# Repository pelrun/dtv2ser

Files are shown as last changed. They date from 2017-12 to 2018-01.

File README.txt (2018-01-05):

README.txt

        dtv2ser - a serial bridge device for the dtvtrans protocol

            written by Christian Vogelgsang <chris@vogelgsang.org>
            under the GNU Public License V2
            
            Homepage: http://www.lallafa.de/blog

Abstract
--------

dtvtrans is a data transfer tool and a PC parallel port cable that allows to
directly read or write memory from a DTV (a.k.a. C64 in a Joystick) via its
joystick or userport. dtvtrans is developed by Daniel Kahlin/TLR and
available here:

  http://www.kahlin.net/daniel/dtv/cable.php

dtv2ser is a small hardware device that implements the dtvtrans protocol on an
Atmel ATmega8 microcontroller. The transferred data is then passed through a
RS232 high speed serial link to a connected client computer. With this device
all PCs with RS232 can use the dtvtrans protocol. With a serial-to-USB adapter
the dtv2ser device can be connected to almost all modern hardware. The new
dtv2usb device directly combines the serial-to-USB adapter and is realized
on a small USB stick like board.

The data flow is as follows:

 DTV  <--[dtvtrans]-->  dtv2ser  <--[RS232]--> serial-to-usb <--[USB]--> client PC
                        +--------------------v-------------+
                                          dtv2usb

Features
--------
 
The dtv2ser package currently consists of the following parts:

 1.) Hardware
  - 0.2: a new schematic for an ATmega8 based board with included USB serial 
    converter using a FT 232 RL chip: dtv2usb
  - 0.2: ready-made board layout for a dtv2usb "stick-like" SMD board
  - a schematic for a minimal ATmega8 board: dtv2ser with MAX232A based 
    RS232 connection
  - both boards running at 14.54760 MHz
  - 3 LEDs for Status: "Ready" (green), "Transmit" (yellow), "Error" (red)
  - wiring for the dtvtrans DB-9 connector
  - on board 10 pin ISP connector that is also used for the bootloader jumper,
    an optional reset switch and optional external power supply.
  - dtv2usb: on board 3 pin power selector: either from USB or external
  - 0.5: added Arduino 2009 board support.
  - 0.6: added ARM blue pill port (see README.arm.txt)
  --> see hardware/ directory
 
 2.) dtv2ser Server Firmware
  - implements all dtvtrans commands
  - a full featured firmware with rich command set
  - full description of the dtv2ser serial protocol (see doc/dtv2ser-proto.txt)
  - high speed UART serial transfer up to 230.4 kbps
  - hardware RTS/CTS handshaking, 8 bit data, parity none, 1 stop bit
  - config parameters settable during runtime and storable in EEPROM
  - added a bootloader to update the firmware directly via serial without ISP
  --> see server/ directory
 
 3.) dtv2sertrans Client Tool
  - dtv2sertrans command line tool (similar to original dtvtrans tool)
  - python module for dtv2ser communication
  - portable: runs on Mac, Linux and Windows
  - requires PySerial (http://pyserial.sourceforge.net/)
  --> see client/ directory

 NOTE: for Linux Users with dtv2ser+usb Hardware:
  the linux kernel driver for the FT232RL device is broken in some
  kernel releases! with those dtv2sertrans won't work!
  tested ok:    2.6.18
  tested ERROR: 2.6.22
  tested ok:    2.6.24

More Documentation
------------------

In the "docs" directory you will find more documentation on this project.

Here is a summary:

  dtv2ser-setup.txt         Setup your dtv2ser device and the dtv2sertrans
                            client command
                            
  dtv2ser-examples.txt      Usage examples of the dtv2sertrans command tool
  
  dtv2ser-joystick.txt      The new joystick, auto type and bootstrap
                            features added in version 0.3
  
  dtv2ser-proto.txt         A detailed description of the low level dtv2ser
                            protocol used by the host PC to communicate with
                            the dtv2ser device.

  avr-toolchain.txt         The commands I used to build a cross compiler
                            toolchain used to compile the server firmware.

Hardware Documents (located in the "hardware" directory):

  dtv2ser.pdf/.png          Schematics of the dtv2ser board
  dtv2ser.sch               Eagle schematic of dtv2ser board
  
  dtv2usb-sch.pdf/.png      Schematics of the dtv2ser+usb board
  dtv2usb-sch.sch           Eagle schematic of dtv2ser+usb board
 
  dtv2usb-manual.txt        Usage instructions for the dtv2ser+usb device
  dtv2usb-parts.txt         Parts list for the dtv2ser+usb device

  dtv2ser-arduino.txt       Instructions for Arduino 2009 HW setup

Have Fun,
-chris/lallafa
2.3.2008

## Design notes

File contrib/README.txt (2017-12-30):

The files found here are directly taken from the dtvtrans-1.0.zip source
archive and provided here for your convenience.

All credits are due to Daniel Kahlin/TLR, the original author.
The original archive is found here: http://www.kahlin.net/daniel/dtv/cable.php

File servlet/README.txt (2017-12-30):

README.txt
----------

This directory contains the assembler source code for 'servlets' that run on
the DTV. A servlet is first downloaded to the DTV memory and then a sys call
is launched.

You need the DASM assembler to build the source:
http://dasm-dillon.sourceforge.net/

The following servlets are available:

 * diag_srv.asm
   
   a small test program used for the diag sys command.
   
   org: 0x1000
   in:  ACC=<number of frames to execute>
   out: ACC=42
        XR=<number of frames to execute>
        YR=0

 * flash_srv.asm
 
   a helper for the flash operations.
   
   the source includes flash_io.asm written by Daniel Kahlin/TLR
   and was taken from his flash-1.0.zip source distribution.
   see: http://www.kahlin.net/daniel/dtv/flash.php
   
   commands in servlet:

   id:  identify flash
   org: 0x1000
   in:  -
   out: ACC = flash type

   id:  generate flash map
	 org: 0x1003
	 in:  -
	 out: 0x2000-0x2800  flash map in ASCII
   
   id:  flash operation
   org: 0x1006
   in:  ACC = mode (0=erase 1=program 2=verify 3=check_empty)
        0x2000-0x2002: <start lsb>,<start csb>,<start msb>
        0x2003-0x2005: <end lsb>,<end csb>,<end lsb>
   out: ACC = error (0=ok)
        XR  = check_empty_result ($ff=empty)

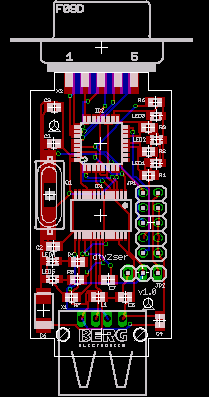
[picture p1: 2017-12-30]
hardware/dtv2usb-brd.png

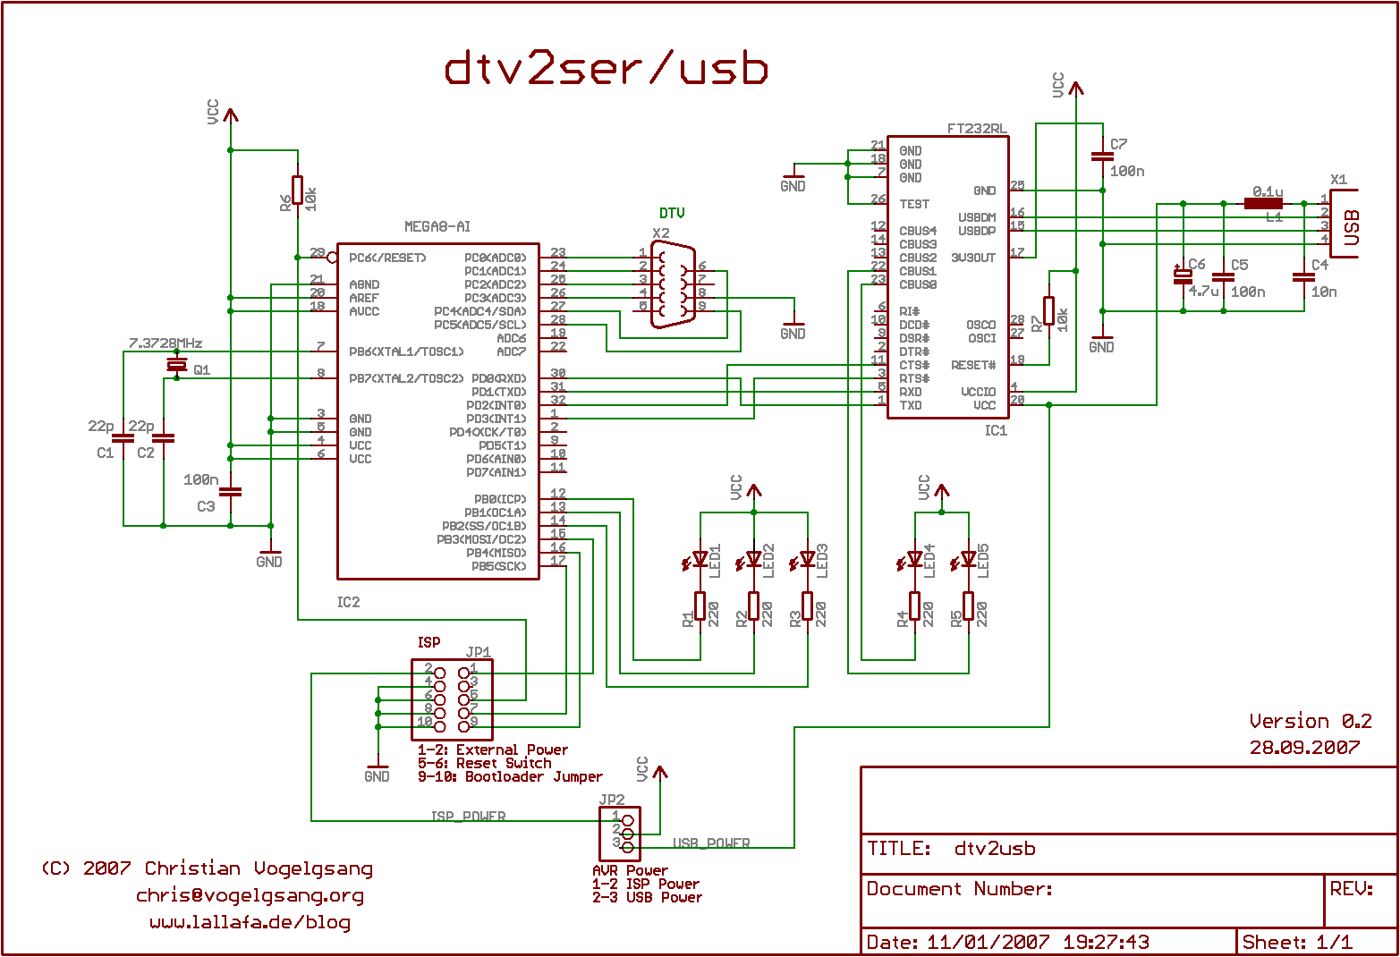
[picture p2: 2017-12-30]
hardware/dtv2usb-sch.png

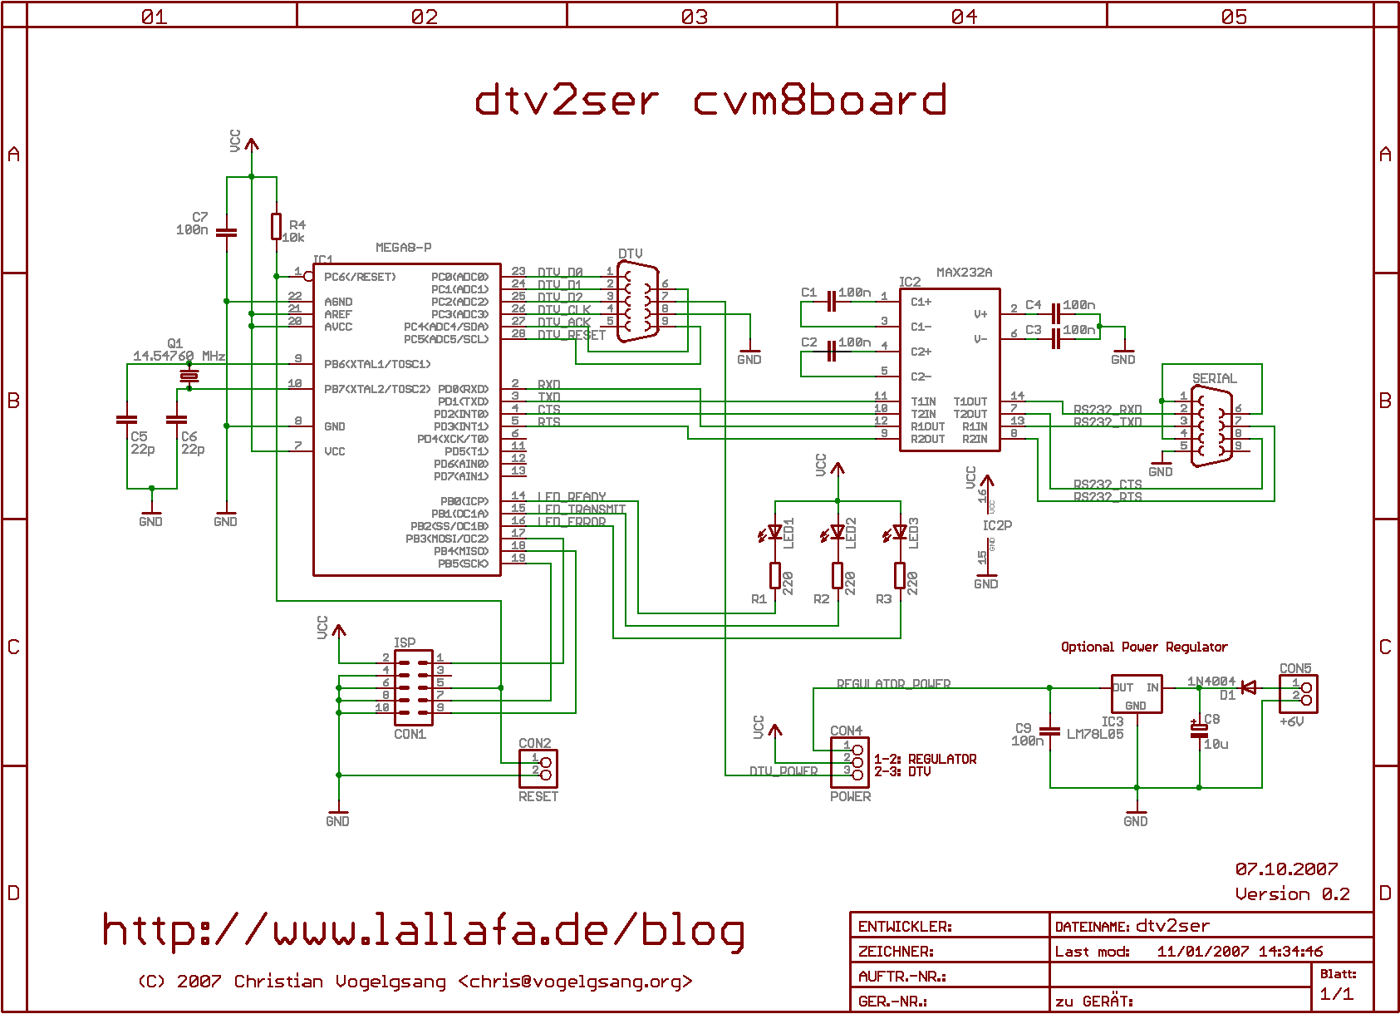
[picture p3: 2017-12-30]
hardware/dtv2ser.png

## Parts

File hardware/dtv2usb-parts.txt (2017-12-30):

Partlist for dtv2usb board
--------------------------

v0.2 26.11.07 chris

Part     Value                    Reichelt.de Parts

C1       22p                      NPO-G0805 22P
C2       22p                      NPO-G0805 22P
C3       100n                     X7R-G0805 100N
C4       10n                      X7R-G0805 10N
C5       100n                     X7R-G0805 100N
C6       4.7u                     SMD TAN.4,7/25
C7       100n                     X7R-G0805 100N

IC1      FT232RL                  FT 232 RL
IC2      MEGA8-AI                 ATMEGA 8-16 TQ

JP1                               SL 1X36G 2,54
JP2                                " + 2x JUMPER 2,54 SW

L1       0.1u                     JCI 2012 0,1µ

LED1     green                    SMD-LED 0805 GN
LED2     yellow                   SMD-LED 0805 GE
LED3     red                      SMD-LED 0805 RT
LED4     green                    SMD-LED 0805 GN
LED5     yellow                   SMD-LED 0805 GE

Q1       7.3728MHz/
         14.7456MHz               14,7456-HC49-SMD

R1       220                      SMD-0805 220
R2       220                      SMD-0805 220
R3       220                      SMD-0805 220
R4       220                      SMD-0805 220
R5       220                      SMD-0805 220
R6       10k                      SMD-0805 10,0K
R7       10k                      SMD-0805 10,0K

X1       USB Type A male          USB AWF
X2       D-SUB 9 female           D-SUB BU 09

Remark: Mount the USB plug (X1) on the bottom side of the board!
        If you use a less common USB Type A female connector then you
        mount it on the top side.

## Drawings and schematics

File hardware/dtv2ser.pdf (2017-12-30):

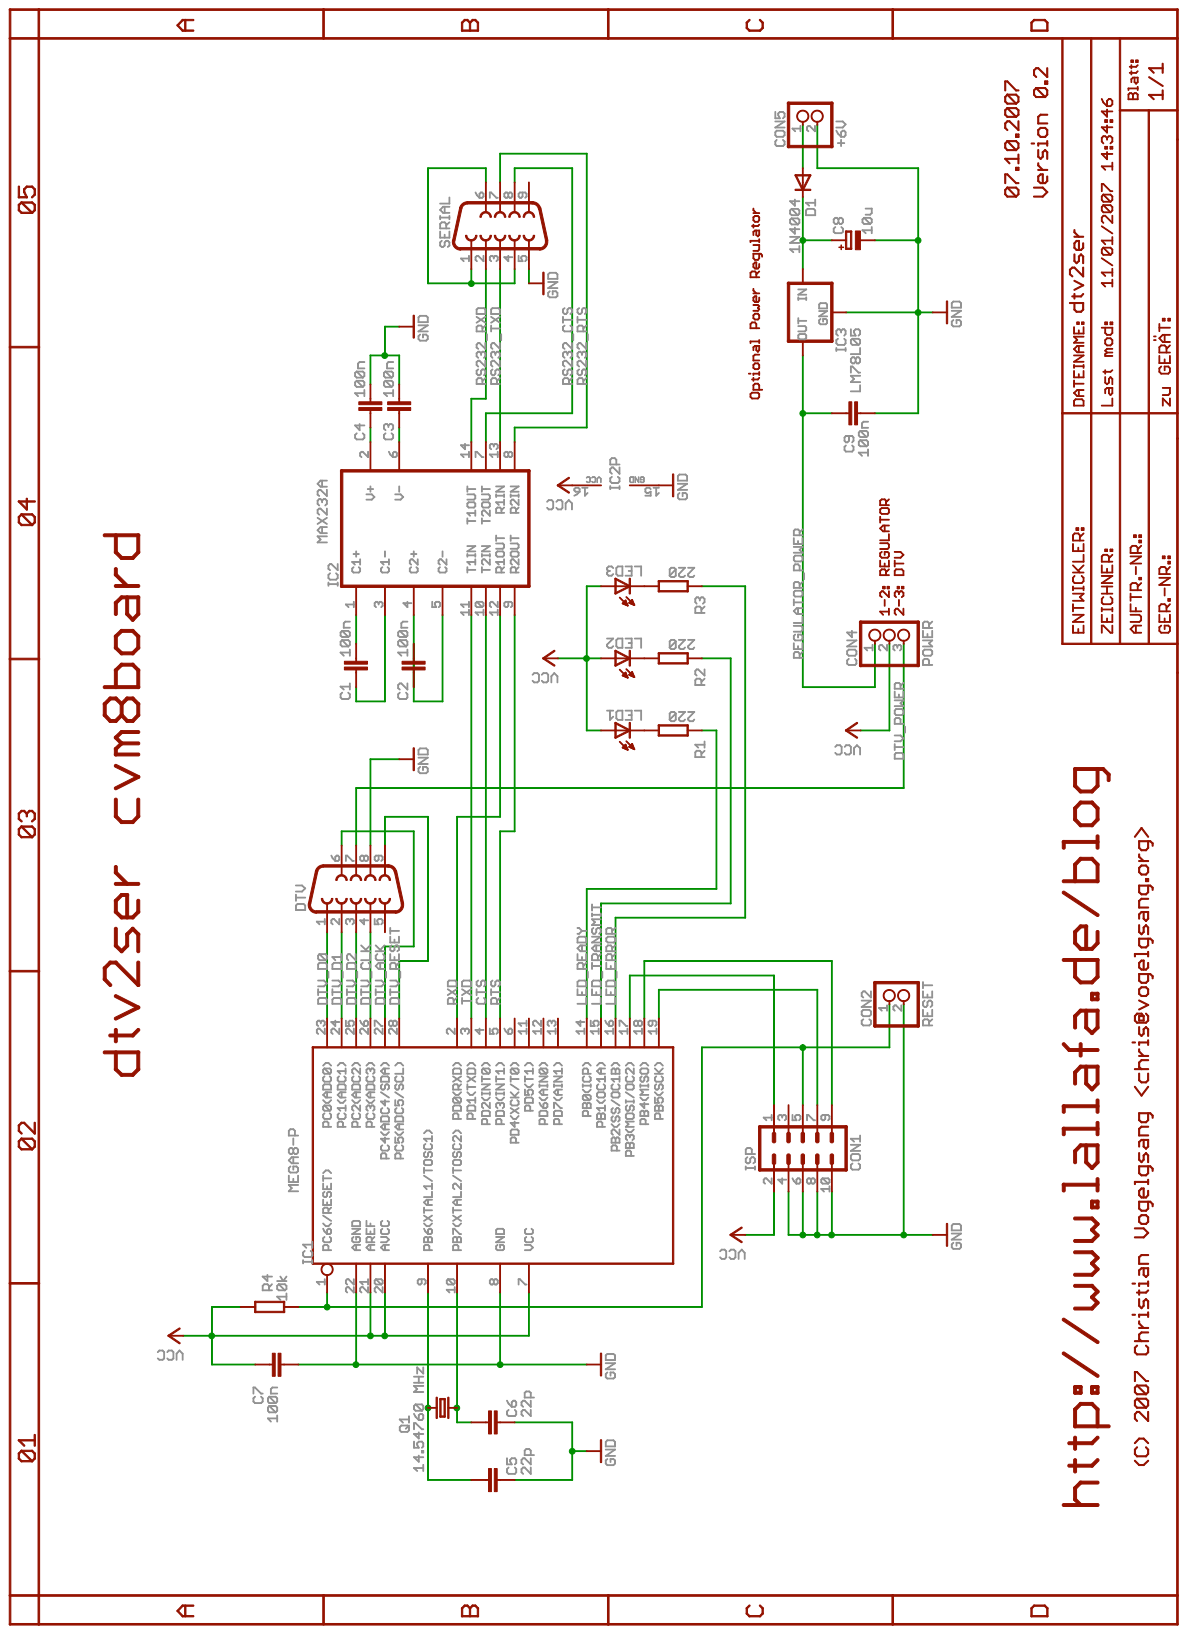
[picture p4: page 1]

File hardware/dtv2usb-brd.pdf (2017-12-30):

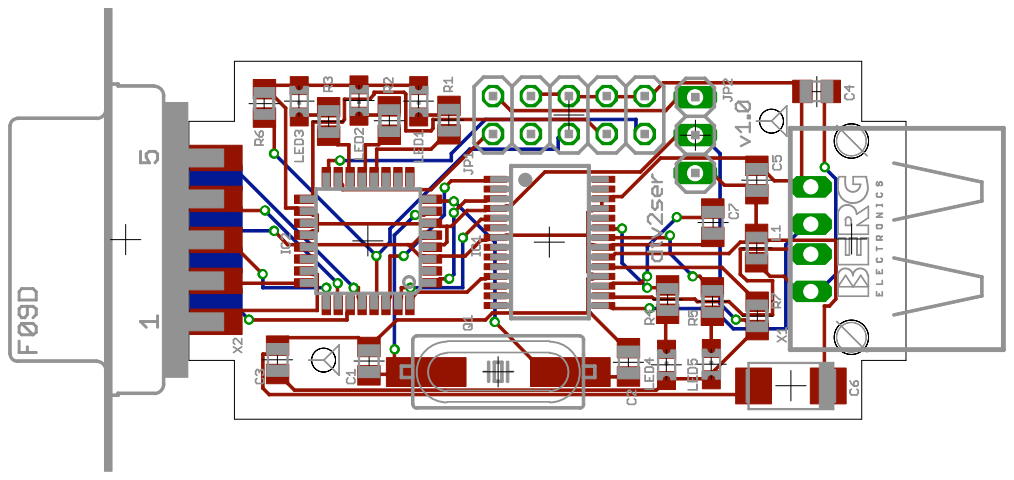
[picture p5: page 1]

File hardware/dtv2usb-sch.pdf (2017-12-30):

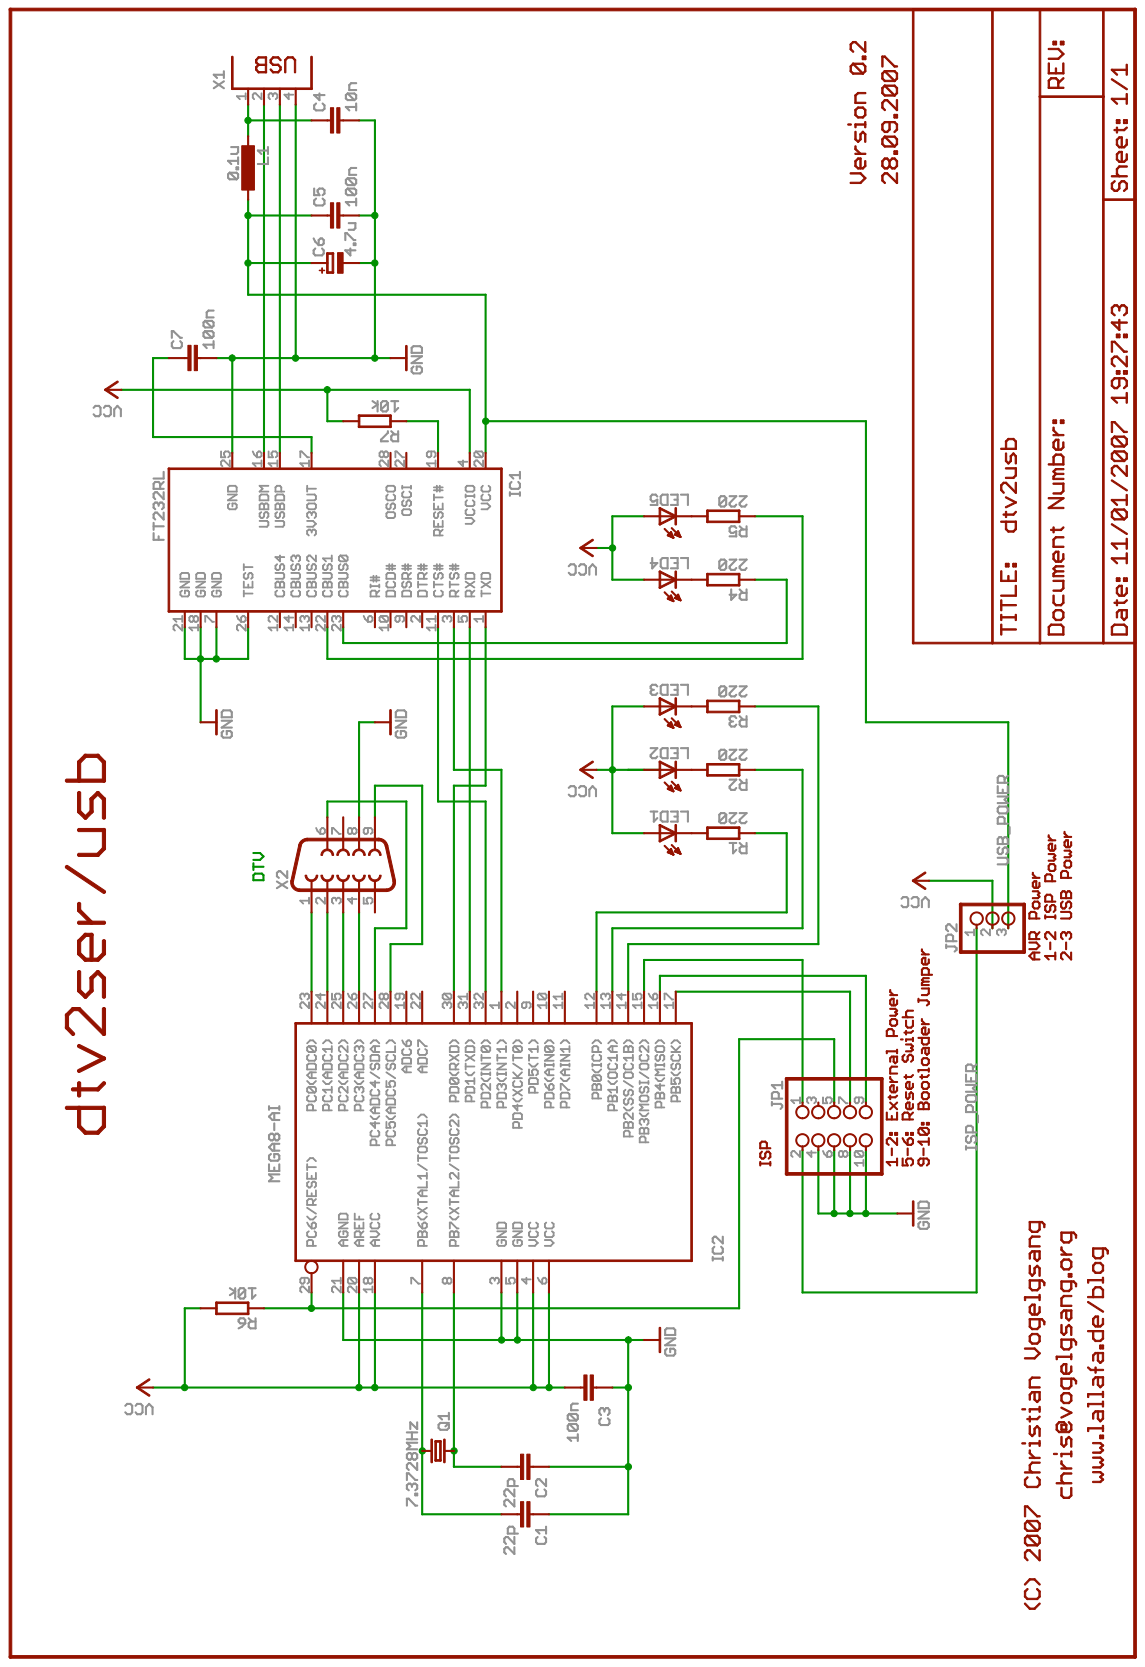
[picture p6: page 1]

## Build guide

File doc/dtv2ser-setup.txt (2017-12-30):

dtv2ser-setup.txt

Hardware Setup
--------------

 1.) build the dtv2ser or the dtv2usb hardware 
     (see hardware/dtv2usb-manual.txt if you own a dtv2ser+usb device)

 2a.) connect your device to the PC and
      flash the bootloader onto the ATmega8 with an ISP:
 
       > cd server
       > make prog_bootloader
 
 2b.) flash the correct fuse bits on a new device:
 
       > make prog_fuse
       
 2c.) set the bootloader jumper on the device and power it.
      now the yellow transfer LED should be lit.
       
 2d.) flash the server firmware onto the ATmega8 via the bootloader

       > cd server
       > make help
       > make prog_dist FILE=flash/dtv2ser-0.1-115200-cvm8board-atmega8.hex

     make sure to choose the correct baud rate for later operation (here 115.2 kbps)!
     repeat steps 2c.) and 2d.) to update your firmware.

 2e.) detach device and unset the bootloader jumper
     
 3.) modify your DTV to supply power and reset on your DB9 joystick connector:
 
      PIN 1    D0
      PIN 2    D1
      PIN 3    D2
      PIN 4    CLK
      PIN 5    N/C
      PIN 6    ACK
      PIN 7    +5V    <-------- add this (only for 0.1 MAX based HW)
      PIN 8    GND
      PIN 9    DTV Reset <----- and this

 4.) attach the dtv2ser via the DB9 joystick connector to the DTV and power on.
     if the green LED goes on then it looks good!
 
 5.) attach your client Mac/PC via RS232 to the dtv2ser device or
     attach the dtv2usb directly via USB.
     launch your favorite terminal application (e.g. Z-Term or Hyperterm)
     
     set the connection values to: 115200 baud, 8 data bit, 1 stop bit,
     parity none and RTS/CTS hardware hand shaking.
     
     enter a 'v' and press return
     
     the dtv2ser/usb should answer with a version string
     
     close the terminal application
     
Software Setup
--------------
     
 1.) install Python on your system (http://www.python.org) and the
     PySerial module (http://pyserial.sourceforge.net/)

 2.) enter the 'client' directory and call './dtv2sertrans' (Mac/Linux)
     or 'python dtv2sertrans' (Windows)
 
     dtv2sertrans will connect to the dtv2ser server and return its firmware
     version.
 
     if the connection to the dtv2ser server fails then set the environment
     variables:
     
       DTV2SER_PORT          serial port device (e.g. /dev/ttyUSB0 on Linux)
       DTV2SER_SPEED         your baud rate (e.g. 115200)
 
     or use the -p and -s switches of dtv2sertrans.

 3.) run the testsuite:
 
     > dtv2sertrans diag testsuite
     
     this will perform a number of test transfers and tests all functionality
     of the dtv2ser device.
     
     if the device passes all tests then you are ready to go!

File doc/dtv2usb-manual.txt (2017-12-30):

dtv2usb Manual
--------------

v0.2 26.11.07 chris

1. Introduction

This manual summarizes the usage of the dtv2usb board described in the
dtv2usb.sch and dtv2usb.brd Eagle (from www.cadsoft.de) files.

2. Hardware Setup

2.1 Overview

On the board there are two pin heads labeled JP1 and JP2.

JP1 is used to connect an AVR ISP to initially flash the bootloader or the
firmware of the ATmega8. Later the JP1 pins can be used to connect an external
(optional) reset button and place a jumper to enter the bootloader mode:

      ^^^ DB9 Connector ^^^

      JP1   1o o
             o o
             x x   <-- Reset button connector
             o o
             *-*   <-- Bootloader Jumper (place and reset to enter bootloader)
             
JP2 is used to select the power source of the dtv2usb board:

      ^^^ DB9 Connector ^^^

      JP2    o o o
      
             *-* o  <-- Power via USB (normal operation)
             o *-*  <-- Power via ISP connector (only used for ISP flash)

There are five LEDs on the board:

      ^^^ DB9 Connector ^^^
      
                      LED3 *    Error (red)
                      LED2 *    Transmit/Bootloader (yellow)
                      LED1 *    Ready (green)

      * LED4  RS232 Tx (yellow)
      * LED5  RS232 Rx (green)

2.2 Initial Flash Operation

On a fresh dtv2board, the ATmega8 needs a bootloader flashed via the ISP
connector. You need an ISP programmer (e.g. the USBasp 
http://www.fischl.de/usbasp/) for this:

  - disconnect the dtv2usb
  - place JP2 to ISP power (see 2.1)
  - attach the ISP with a 10 pin cable to JP1 (pin 1 at top left of JP1)
  - attach the ISP via USB to your PC
  - enter "server" directory of this distribution within a shell and call:

      > make prog_bootloader

  - use AVRDUDE_ISP_PROGRAMMER and AVRDUDE_ISP_PORT to select your programmer:

      > make prog_bootloader AVRDUDE_ISP_PROGRAMMER=usbasp AVRDUDE_ISP_PORT=

Now the ATmega8 needs the correct fuse bits set:

      > make prog_fuse

  - again you can use AVRDUDE_ISP_PROGRAMMER and AVRDUDE_ISP_PORT to config
    your ISP.

Disconnect your ISP now and set the power connector JP2 back to normal
operation (see 2.1)

2.3 Bootloader Mode

You need to enter Bootloader Mode to flash a new firmware version directly via
the USB port without any external ISP.

  ** enter bootloader mode:

  - disconnect dtv2usb from the PC and the DTV
  - place the bootloader jumper on JP1 (see 2.1)
  - make sure JP2 is set to USB power
  - attach the dtv2usb only to your PC
  
  - the orange LED2 is now lit and signals that the bootloader mode is active
  
  ** flash the firmware
  
  - enter the "server" directory of this distribution and call:
  
    make prog_dist FILE=flash/dtv2ser-<version>-230400-cvm8board-atmega8.hex \
                   AVRDUDE_BOOTLOADER_PORT="-P /dev/cu.usbserial-*"
    
    set the bootloader port to the correct virtual serial port that was
    assigned to the dtv2ser. This varies on every system. Use your favorite
    USB inspector tool to find this out.
    
  - now the firmware is flashed
  
  ** leave bootloader mode:
  
  - disconnect dtv2usb from the PC
  - remove the bootloader jumper on JP1 (see 2.1)
  - attach the dtv2usb to your PC
  
  - the green LED1 is now lit and signals that the dtv2ser firmware operates
    normally and bootloader mode was left successfully

2.4 Normal Operation

  - make sure the bootloader jumper on JP1 is removed (see 2.1)
  - make sure the power jumper JP2 is set to normal operation (see 2.1)
  
  ** attach the dtv2usb
  
  - power off the DTV
  - attach the dtv2usb to the DTV's joystick port (usually port 2)
  - attach the dtv2usb via USB (and an optional USB extension cord) to your host
  - the green LED1 of the dtv2usb is now lit
  - power on the DTV
  
  ** detach the dtv2usb

  - remove the dtv2usb from the USB port of the PC
  - power off the DTV
  - remove the dtv2usb from the DTV's joystick port

2.5 Hardware Test

  - set up normal operation (see 2.4)
  - enter the "client" directory of this distribution
  - call:
  
      ./dtv2sertrans -p /dev/cu.usbserial-* -s 230400 reset + diag testsuite
      
    Make sure to set the correct serial port with -p and the correct
    serial speed (-s) you flashed in the firmware!

    This command sequence will reset the DTV and enters dtvtrans mode
    automatically (assuming you have DTVmon >= 1.1 installed).
    Then it performs a series of internal and external transfer tests.
    
THE END

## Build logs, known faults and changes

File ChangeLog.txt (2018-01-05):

version 0.6 - 5.1.2018

 dtv2sertrans:
  * improved startup communications to make it more robust

 dtv2ser protocol:
  * remove OOB signalling using CTS - CTS is now for flow control only,
    protocol uses only the data on the line. Allows use of generic serial
    transports e.g. bluetooth or usb that synthesise flow control signals at
    each end.

 dtv2ser firmware:
  * Refactoring to separate AVR-specific code to allow porting
  * ARM port for the STM32F103 blue pill board ($2)
  * Remove joystream constraints - can now be used to relay joystick control
    from the PC end.
  * Refactor timebase to 1ms instead of split 100us/10ms. This requires
    stored parameters to be reset to new defaults.

version 0.5 - 11.12.2010

 dtv2sertrans:
  * fixed double open problem in pySerial on Windows
  * added missing 'g' command available in TLR's dtvtrans for usage compatibility  

 dtv2ser firmware:
  * added support for Arduino 2009 board (ATmega168, 16 MHz, 250kB/s transfer)

version 0.4 - 14.9.2008

 dtv2sertrans:
  * rewrote whole application and added a more generic command handler
  * added flash sub commands
  * added state tracking of dtvtrans server
  * added dtvtrans 1.0 commands, e.g. exit, init, load, run, save
  * added fill command to fill memory of DTV
  * added info command to query server information
  * added ping command to perform is-alive check of server
  * changed sys command now uses dtvtrans 1.0 sys, waits for result and
    does a sys_result to query the result values
  * added sys call diagnose to test reliability of sys call feature
  
 dtv2ser protocol:
  * due to size contraints: redesigned and streamlined protocol
  * added 'm' transfer mode command that replaces debug transfer commands
  * added 'a' is-alive check to query if server has a running dtvtrans
  * replaced all old dtvtrans commands with generic 'c' dtvtrans command

 dtv2ser firmware:
  * replaced debug transfer commands with one transfer routine that
    uses a toggle command to determine data flow
  * dtvtrans commands are not handled in the dtv2ser device anymore.
    commands are triggered with 'c' and the client passes all arguments and
    afterwards picks up the resulting output
  
version 0.3 - 2.3.2008
 
 dtv2sertrans:
  * fixed serial setup for windows
  * added 'bootstrap' command
  * added 'joy stream/type/wiggle' commands
  * added AutoType generator
  * added Screen Code compiler
  * added local command switches, e.g.: bootstrap -s full
  * added automatic file type detection by extension (*.bin, *.raw, *.prg)
  * added output of total transfer time and size
  
 dtv2ser protocol:
  * removed 't*' and replaced it with a single 't' command
  * removed command argument verification to save space
  * added 'js' command
  * added new data transfer protocol for read/write mem and boot
  * added transfer protocol for joystream
  
 dtv2ser firmware:
  * cleaned up and stream-lined command execution
  * added joystick output
  * added joystream execution
  * new RTS/CTS serial reception handling for fast dtvtrans 1.0 transfers

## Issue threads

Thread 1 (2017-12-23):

Remove OOB signalling via CTS

pelrun, 2017-12-23:
Assuming that CTS will perfectly track the signal being sent from the dtv2ser device is a bad idea. Hardware handshaking isn't directly relayed through many types of serial transport, but are synthesised at either end (e.g. when local buffers are full.) So I can't use this as is with a Bluetooth link, or anything except a specific FTDI configuration, and that only works because FTDI uses custom drivers instead of the standard USB CDC protocol.

So rip it out and use in-band responses to determine the state of the link.

pelrun, 2017-12-28:
Closed by eba3a4

Closed 2017-12-28.

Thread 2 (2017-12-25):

Add retries for transfers

pelrun, 2017-12-25:
Currently aborts an entire transfer if a single block fails checksum. Needs to restart the transfer from the failed block.

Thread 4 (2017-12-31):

Fix broken parameter storage

pelrun, 2017-12-31:
Once parameters are saved in eeprom something is reloading the parameters at the wrong time and wiping out any modifications, effectively rendering the parameters read-only.

pelrun, 2017-12-31:
This is due to the arduino reset-on-connect behaviour. Parameters in RAM only stay valid during a single command session. Considering whether to just save params on any change.

pelrun, 2018-01-03:
The ARM port currently only fakes parameter storage, as there is no EEPROM available. Honestly it's unnecessary to change these in normal usage, so I'm leaning towards this being a WONTFIX.

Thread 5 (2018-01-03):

Improve usb->host transfer

pelrun, 2018-01-03:
ARM port currently sends data to the host one byte per packet (!). Initial attempts to fix this have caused a nasty
race condition, so have been disabled.

Batched transfers need to periodically clear the buffer after a timeout, but running the flush task periodically in interrupt context occasionally sends a buffer twice. Probably need to set up a watchdog that gets reset every time a flush in normal context happens, so that no unnecessary flushes are attempted.

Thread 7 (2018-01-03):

Race condition in syscall

pelrun, 2018-01-03:
Looks like the dtvtrans server on the dtv waits for the joystick lines to be released by dtv2ser before executing the command. This isn't being done in dtvtrans_command(), so any dtv2ser command sent from the host immediately afterwards ('a' is the main culprit) can block the previous command until a timeout happens.

Currently worked around by putting a small delay on the python side, but it really needs to happen in dtvtrans_command() so command processing is halted until the dtvtrans command is guaranteed to have started.

pelrun, 2018-01-03:
Fixed by 8afbf49

Closed 2018-01-03.

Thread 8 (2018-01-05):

Integrate IEC drive relay functionality to ARM port

pelrun, 2018-01-05:
There's plenty of CPU/Flash/free pins on the blue pill, so there's no reason to use extra hardware when the
board can do both dtvtrans and uno2iec at once...

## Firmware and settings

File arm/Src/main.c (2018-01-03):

/**
  ******************************************************************************
  * File Name          : main.c
  * Description        : Main program body
  ******************************************************************************
  * This notice applies to any and all portions of this file
  * that are not between comment pairs USER CODE BEGIN and
  * USER CODE END. Other portions of this file, whether 
  * inserted by the user or by software development tools
  * are owned by their respective copyright owners.
  *
  * Copyright (c) 2017 STMicroelectronics International N.V. 
  * All rights reserved.
  *
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
  ******************************************************************************
  */

/* Includes ------------------------------------------------------------------*/
#include "main.h"
#include "stm32f1xx_hal.h"
#include "usb_device.h"
#include "gpio.h"

/* USER CODE BEGIN Includes */

#include "board.h"

#include "display.h"
#include "cmdline.h"
#include "uart.h"
#include "uartutil.h"
#include "timer.h"
#include "dtvlow.h"
#include "param.h"

/* USER CODE END Includes */


/* USER CODE BEGIN PV */

/* USER CODE END PV */

void SystemClock_Config(void);

/* USER CODE BEGIN PFP */

/* USER CODE END PFP */

int main(void)
{

  /* MCU Configuration----------------------------------------------------------*/

  /* Reset of all peripherals, Initializes the Flash interface and the Systick. */
  HAL_Init();

  /* Configure the system clock */
  SystemClock_Config();

  /* Initialize all configured peripherals */
  MX_GPIO_Init();
  MX_USB_DEVICE_Init();

  /* USER CODE BEGIN 2 */

  // board init. e.g. switch off watchdog
  board_init();
  
  // setup HW
  led_init();
  
  // setup timer
  timer_init();

  // setup serial
  uart_init();

  // dtvtrans interface init
  dtvlow_state_clear();
  
  // setup parameters
  param_init();
  
  // init cmdline
  cmdline_init();
  
  /* USER CODE END 2 */

  /* Infinite loop */
  /* USER CODE BEGIN WHILE */
  while (1)
  {
  /* USER CODE END WHILE */

  /* USER CODE BEGIN 3 */
    cmdline_handle();
  }
  /* USER CODE END 3 */

}

/** System Clock Configuration
*/
void SystemClock_Config(void)
{

  RCC_OscInitTypeDef RCC_OscInitStruct;
  RCC_ClkInitTypeDef RCC_ClkInitStruct;
  RCC_PeriphCLKInitTypeDef PeriphClkInit;

    /**Initializes the CPU, AHB and APB busses clocks 
    */
  RCC_OscInitStruct.OscillatorType = RCC_OSCILLATORTYPE_HSE;
  RCC_OscInitStruct.HSEState = RCC_HSE_ON;
  RCC_OscInitStruct.HSEPredivValue = RCC_HSE_PREDIV_DIV1;
  RCC_OscInitStruct.HSIState = RCC_HSI_ON;
  RCC_OscInitStruct.PLL.PLLState = RCC_PLL_ON;
  RCC_OscInitStruct.PLL.PLLSource = RCC_PLLSOURCE_HSE;
  RCC_OscInitStruct.PLL.PLLMUL = RCC_PLL_MUL6;
  if (HAL_RCC_OscConfig(&RCC_OscInitStruct) != HAL_OK)
  {
    _Error_Handler(__FILE__, __LINE__);
  }

    /**Initializes the CPU, AHB and APB busses clocks 
    */
  RCC_ClkInitStruct.ClockType = RCC_CLOCKTYPE_HCLK|RCC_CLOCKTYPE_SYSCLK
                              |RCC_CLOCKTYPE_PCLK1|RCC_CLOCKTYPE_PCLK2;
  RCC_ClkInitStruct.SYSCLKSource = RCC_SYSCLKSOURCE_PLLCLK;
  RCC_ClkInitStruct.AHBCLKDivider = RCC_SYSCLK_DIV1;
  RCC_ClkInitStruct.APB1CLKDivider = RCC_HCLK_DIV2;
  RCC_ClkInitStruct.APB2CLKDivider = RCC_HCLK_DIV1;

  if (HAL_RCC_ClockConfig(&RCC_ClkInitStruct, FLASH_LATENCY_1) != HAL_OK)
  {
    _Error_Handler(__FILE__, __LINE__);
  }

  PeriphClkInit.PeriphClockSelection = RCC_PERIPHCLK_USB;
  PeriphClkInit.UsbClockSelection = RCC_USBCLKSOURCE_PLL;
  if (HAL_RCCEx_PeriphCLKConfig(&PeriphClkInit) != HAL_OK)
  {
    _Error_Handler(__FILE__, __LINE__);
  }

    /**Configure the Systick interrupt time 
    */
  HAL_SYSTICK_Config(HAL_RCC_GetHCLKFreq()/1000);

    /**Configure the Systick 
    */
  HAL_SYSTICK_CLKSourceConfig(SYSTICK_CLKSOURCE_HCLK);

  /* SysTick_IRQn interrupt configuration */
  HAL_NVIC_SetPriority(SysTick_IRQn, 0, 0);
}

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


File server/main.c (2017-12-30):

/*
 * main.c - main loop
 *
 * Written by
 *  Christian Vogelgsang <chris@vogelgsang.org>
 *
 * This file is part of dtv2ser.
 * See README for copyright notice.
 *
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
 */

#include <stdint.h>

#include "board.h"

#include "display.h"
#include "cmdline.h"
#include "uart.h"
#include "uartutil.h"
#include "timer.h"
#include "dtvlow.h"
#include "param.h"

int main (void){
  // board init. e.g. switch off watchdog
  board_init();

  // setup HW
  led_init();

  // setup timer
  timer_init();

#ifdef USE_LCD
  lcd_init();
#endif

#ifdef USE_BEEPER
  beeper_init();
#endif

  // setup serial
  uart_init();

  // dtvtrans interface init
  dtvlow_state_clear();

#ifdef USE_BEEPER
  // welcome beep
  beeper_beep(1);
#endif
#ifdef USE_LCD
  // welcome message
  lcd_clear();
  lcd_print_version();
#endif

  // setup parameters
  param_init();

  // init cmdline
  cmdline_init();
  // main loop
  while(1) {
    cmdline_handle();
  }

  return 0;
}

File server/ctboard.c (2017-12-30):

/*
 * ctboard.c - c't board hardware access
 *
 * Written by
 *  Christian Vogelgsang <chris@vogelgsang.org>
 *
 * This file is part of dtv2ser.
 * See README for copyright notice.
 *
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
 */

#include <stdint.h>

#include <avr/io.h>
#include <util/delay.h>

#include "ctboard.h"

// ---------- DELAY ---------------------------------------------------------

#ifdef CT_BOARD_DELAY

void ct_delay(uint8_t num)
{
  uint8_t counter;
  for(counter=0;counter<num;counter++) {
    _delay_loop_2(30000);
    counter++;
  }
}

#endif

// ---------- KEYS & LEDS ---------------------------------------------------

#ifdef CT_BOARD_KEYS
static uint8_t key_state;
#endif

void led_init(void)
{
  DDRD |= CT_LED_ALL;	// led output
  PORTD |= CT_LED_ALL;
#ifdef CT_BOARD_KEYS
  key_state = 0;
#endif
}

void led_on(uint8_t led_mask)
{
  PORTD &= ~led_mask;
}

void led_off(uint8_t led_mask)
{
  PORTD |= led_mask;
}

#if 0
void ct_led_bits(uint8_t bits)
{
  bits = (~bits & 0xf) << 3;
  PORTD &= ~ CT_LED_ALL;
  PORTD |= bits;
}
#endif

#ifdef CT_BOARD_KEYS

uint8_t ct_read_keys(void)
{
  // read old led state
  uint8_t oldPORTD = PORTD;
  uint8_t result;

  // disable outputs of leds and activate pullups
  DDRD &= ~CT_LED_ALL;
  PORTD |= CT_LED_ALL;

  // read in key pins
  result = ~PIND & CT_LED_ALL;

  // restore output led state
  DDRD |= CT_LED_ALL;
  PORTD = oldPORTD;
  return result;
}

uint8_t ct_get_key_press()
{
  uint8_t i,j,changed;

  // read initial keystate
  uint8_t new_key_state = ct_read_keys();

  // no keys pressed -> return 0
  if(new_key_state == 0) {
    key_state = 0;
    return 0;
  }

  // nothing has changed
  if(new_key_state == key_state) {
    return 0;
  }

  // make sure state is stable
  for(i=0;i<10;i++) {
    uint8_t temp_key_state = ct_read_keys();
    if(temp_key_state != new_key_state)
      return 0;
    for(j=0;j<255;j++) { asm("nop"); }
  }

  // save key state and return changed keys
  new_key_state = ct_read_keys();
  changed = key_state ^ new_key_state;
  key_state = new_key_state;
  return changed;
}

#endif

// ---------- BEEPER --------------------------------------------------------

#ifdef USE_BEEPER

void beeper_init(void)
{
  DDRA|=0x10; // PA4 (beeper) is output
}


static void ct_beep_toggle(void)
{
  PORTA = PORTA ^ 0x10;
}

void beeper_beep(uint8_t num)
{
  uint8_t i;
  for(i=0;i<num;i++) {
    uint8_t j;
    for(j=0;j<100;j++) {
      ct_beep_toggle();
      _delay_loop_2(1000);
    }
    for(j=0;j<100;j++) {
      _delay_loop_2(1000);
    }
  }
}

#endif

// ---------- MPLEX ---------------------------------------------------------

void ct_init_mplex(void)
{
	DDRB|= 0x07; // PB0-PB2 is output
	PORTB &= ~CT_MPLEX_MASK;
	PORTB |= CT_MPLEX_MCU_XPT_COPY_XPT;
}

void ct_set_mplex(uint8_t mode)
{
	uint8_t pb = PORTB & ~CT_MPLEX_MASK;
	PORTB = pb | mode;
}

// ---------- RTS/CTS -------------------------------------------------------

#ifdef USE_XPORT

void ct_xport_init_rts_cts(void)
{
  DDRB  &=  ~0x08; // PB3 is input from XPort/GP1/RTS/output
  PORTB |=   0x08;

  DDRD  |=   0x80; // PD7 is output to XPort/GP3/CTS/input
  PORTD &=  ~0x80; // low active: allow sending from XPort
}

uint8_t ct_xport_get_rts(void)
{
  return (PINB & 0x08) == 0x08;
}

void ct_xport_set_cts(uint8_t on)
{
  if(on)
    PORTD &= ~0x80; // low active: allow sending from XPort
  else
    PORTD |=  0x80; // deny sending from XPort
}

#else

void ct_com_init_rts_cts(void)
{
  DDRD  &=  ~0x04; // PD2 is input from COM/RTS
  PORTD |=   0x04;

  DDRB  |=   0x10; // PB4 is output to COM/CTS
  PORTB &=  ~0x10; // low active!
}

uint8_t ct_com_get_rts(void)
{
  return (PIND & 0x04) == 0x00;
}

void ct_com_set_cts(uint8_t on)
{
  if(on)
    PORTB &= ~0x10; // low active: allow sending from XPort
  else
    PORTB |=  0x10; // deny sending from XPort
}

#endif

// ---------- LCD -----------------------------------------------------------

#ifdef USE_LCD

#define LCD_NOP      asm("nop")

#define DISPLAY_PINS 0x0F
#define DPC        (PORTC & ~DISPLAY_PINS)
#define DRC        (DDRC & ~DISPLAY_PINS)
#define DPC_C(c)   ((PORTC & (~DISPLAY_PINS|~c))) /* c-bit(s) loeschen */
#define DPC_T(s,c) ((PORTC & (~DISPLAY_PINS|~c))|(s & DISPLAY_PINS)) /* s-bit(s) setzen, c-bit(s) loeschen */
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

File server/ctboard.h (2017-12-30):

/*
 * ctboard.h - c't board hardware access
 *
 * Written by
 *  Christian Vogelgsang <chris@vogelgsang.org>
 *
 * This file is part of dtv2ser.
 * See README for copyright notice.
 *
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
 */

#ifndef CTBOARD_H
#define CTBOARD_H

/*
    Port A
	0		<- ANALOG+AMP		(Connector P6)		CT_TEMP0
	1		<- ANALOG+AMP		(Connector P7)		CT_TEMP1
	2		IO8					(Connector P9)		CT_LDR/NTC
	3		IO9					(Connector P10)
	4		IO10	BEEPER							CT_BEEPER
	5		IO11				(A Board?)
	6		IO12				(A Board?)
	7		IO13	XP_CP2/DTR						CT_XP_CP2

	Port B                      uC-COM         XPort-COM          uC-XPort
	0     +                       1          sniff:1=COM,0=XP          0
	1     |-SerialDirection       1               0                    x(1)
	2     +                       x               0                    1
	3		IO14	XP_CP1/RTS	(COM/CTS wenn PB1==0)
	4		IO15				(COM/CTS wenn PB1==1)
	5		MOSI	+ SPI
	6		MISO	+ SPI
	7		SCLK	+ SPI

	Port C
	0		IO0		LCD_DS
	1		IO1		LCD_SHCP
	2		IO2		LCD_STCP
	3		IO3		LCD_BUSY
	4		IO4					(Connector P10)
	5		IO5					(Connector P10)
	6		IO6					(Connector P10)
	7		IO7					(Connector P10)

	Port D
	0		MCU_RXD	+ MCU UART
	1		MCU_TXD	+ MCU UART
	2		IO16	COM_RTS		(XP_CP3 wenn PB2==0)
	3		TL0  	KEY & LED RED
	4		TL1		KEY & LED ORANGE
	5		TL2		KEY & LED YELLOW
	6		TL3		KEY & LED GREEN
	7		IO17				(XP_CP3/CTS wenn PB2==1)
*/

#define DTVLOW_DATA_MASK     0x70
#define DTVLOW_CLK_MASK      0x80
#define DTVLOW_DATACLK_PORT  PORTC
#define DTVLOW_DATACLK_PIN   PINC
#define DTVLOW_DATACLK_DDR   DDRC
#define DTVLOW_DATA_SHIFT    4

#define DTVLOW_ACK_MASK      0x04
#define DTVLOW_RESET_MASK    0x08
#define DTVLOW_ACKRESET_PORT PORTA
#define DTVLOW_ACKRESET_PIN  PINA
#define DTVLOW_ACKRESET_DDR  DDRA

void board_init(void) {}

// ---------- DELAY ---------------------------------------------------------
#ifdef CT_BOARD_DELAY
#define CT_DELAY_100MS	5
#define CT_DELAY_500MS  25
#define CT_DELAY_1SEC   50
void ct_delay(uint8_t num);
#endif

// ---------- KEYS & LEDS ---------------------------------------------------
#define CT_LED_GREEN	0x40
#define CT_LED_YELLOW   0x20
#define CT_LED_ORANGE   0x10
#define CT_LED_RED      0x08
#define CT_LED_ALL      0x78

void led_init(void);
void led_on(uint8_t led_mask);
void led_off(uint8_t led_mask);

// 1. Ready LED (green)
#define led_ready_on()      led_on(CT_LED_GREEN)
#define led_ready_off()     led_off(CT_LED_GREEN)

// 2. Error LED (red)
#define led_error_on()      led_on(CT_LED_RED)
#define led_error_off()     led_off(CT_LED_RED)

// 3. Transmit LED (yellow)
#define led_transmit_on()   led_on(CT_LED_YELLOW)
#define led_transmit_off()  led_off(CT_LED_YELLOW)


//void ct_led_bits(uint8_t num);
#ifdef CT_BOARD_KEYS
uint8_t ct_get_key_press(void);
#endif

// ---------- BEEPER --------------------------------------------------------
#ifdef USE_BEEPER
void beeper_init(void);
void beeper_beep(uint8_t ms);
#endif

// ---------- UART MPLEX ----------------------------------------------------
// COPY_... defines what is transferred to XPT
#define CT_MPLEX_COM_MCU_COPY_COM		0x03
#define CT_MPLEX_COM_MCU_COPY_MCU		0x07
// COPY_... defines what is transferred to MCU
#define CT_MPLEX_COM_XPT_COPY_COM		0x01
#define CT_MPLEX_COM_XPT_COPY_XPT		0x00
// COPY_... defines what is transferred to COM
#define CT_MPLEX_MCU_XPT_COPY_MCU       0x06
#define CT_MPLEX_MCU_XPT_COPY_XPT		0x04
// invalid mplex modes
#define CT_MPLEX_INVALID1				0x02
#define CT_MPLEX_INVALID2				0x05
// bitmask for all mplex bits
#define CT_MPLEX_MASK					0x07
void ct_init_mplex(void);
void ct_set_mplex(uint8_t mode);

// ---------- LCD -----------------------------------------------------------
#ifdef USE_LCD

#define CT_LCD_MODE_OFF         0x08
#define CT_LCD_MODE_ON          0x0c
#define CT_LCD_MODE_ON_CURSOR   0x0e
#define CT_LCD_MODE_ON_BLINK    0x0f

#define CT_LCD_CMD_CLEAR        0x01
#define CT_LCD_CMD_INIT         0x38
#define CT_LCD_CMD_ADDR         0x80

#define CT_LCD_RS_BIT           0x01
#define CT_LCD_RW_BIT           0x02
#define CT_LCD_E_BIT            0x04
#define CT_LCD_D_BIT            0x08

void lcd_init(void);
void lcd_byte(uint8_t cmd, uint8_t cmdOrData);
void lcd_pos(uint8_t x,uint8_t y);
//void ct_lcd_mode(uint8_t mode);
//void ct_lcd_line(uint8_t y,uint8_t *line,uint8_t len);
//void ct_lcd_string(uint8_t *str);

#define lcd_data(a)        ct_lcd_uint8_t(a, CT_LCD_RS_BIT)
#define lcd_cmd(a)         ct_lcd_uint8_t(a, 0)

#define lcd_clear()        ct_lcd_cmd(CT_LCD_CMD_CLEAR)
#define lcd_char(b)        ct_lcd_data(b)

#endif

// ---------- ADC -----------------------------------------------------------
#ifdef CT_BOARD_ADC
uint16_t adc_read(uint8_t channel);
#endif

// ---------- GPIO ----------------------------------------------------------
#ifdef CT_BOARD_GPIO
#define CP_DEF(NUM) \
void ct_set_cp ## NUM ## _dir(uint8_t out); \
uint8_t ct_get_cp ## NUM ## _dir(void); \
void ct_set_cp ## NUM (uint8_t on); \
uint8_t ct_get_cp ## NUM (void);
CP_DEF(1)
CP_DEF(2)
CP_DEF(3)
#endif
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

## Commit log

2017-12-30 Refactor the board dependent code
    Remove the defines that convert the interface functions to board specific
    ones and use the generic interface names in the board specific code.
2017-12-30 Remove unnecessary abort on no input in joystream
    If client wants to manage timing itself it should be able to. Forcing an
    abort doesn't provide any benefits, and blocks some potential use cases.
    [joycmd.c]
2017-12-30 Add simple joystick relay util
    Use WASD and Enter for fire
2017-12-31 Refactor timer code and move to a consistent 1ms timebase
2017-12-31 Add bluepill to board.h
    The rest of the ARM port is in a separate project, this just lets things
    resolve properly.
2018-01-01 Move the joystick mask bits to the HAL
    They're directly used in the serial protocol, so that means the definition
    has to be platform independent. Any board that uses different pins must
    translate instead of modifying these definitions.
2018-01-01 Fix case of inconsistent return value semantics
    Sometimes it's <status>, other times it's (<status>,<duration>)
2018-01-03 Implement joystick control and leds
2018-01-03 Fix USB serial bugs
    Currently sends one byte per packet to the host, first attempts to batch
    them up caused a nasty race condition so it's currently disabled.
    [uart.c]
2018-01-03 Move to arm subdir in preparation for merging repositories
2018-01-03 Fix ARM makefile for merged repo layout
2018-01-03 Fix syscall race condition
    If another command changed the joystick port state too quickly after a
    dtvtrans syscall, it could block the DTV from executing the syscall.
    Ensure that the bus is released long enough before allowing another
    command to be processed.
    [dtvtrans.c]
2018-01-05 Increase version to 0.6 and rename USB device
2018-01-05 Simplify USB RX
    Get rid of the circular buffer now that flow control works properly.
2018-01-05 Add a simple README for the ARM port
2018-01-05 Set up makefile variable to build bootloader-ready version
    make BOOTLOADABLE=1 (0 is currently default, change when tested)

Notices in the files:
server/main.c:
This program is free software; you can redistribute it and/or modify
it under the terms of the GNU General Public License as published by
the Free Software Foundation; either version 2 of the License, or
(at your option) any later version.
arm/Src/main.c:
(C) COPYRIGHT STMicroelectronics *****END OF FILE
